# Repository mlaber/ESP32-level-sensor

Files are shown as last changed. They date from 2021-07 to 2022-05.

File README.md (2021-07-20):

# ESP32-level-sensor
ESP32 ultrasonic measurement for containers, reservoirs, silos ... with prometheus exporter
# ESP32 Ultraschall-Füllstandssensor 

*Messen von Füllständen und Pegel in Regenwasserzisternen, Pools, Fässern, Container, Silos ... mit Prometheus Exporter und einem Grafana Beispiel-Dashboard.*

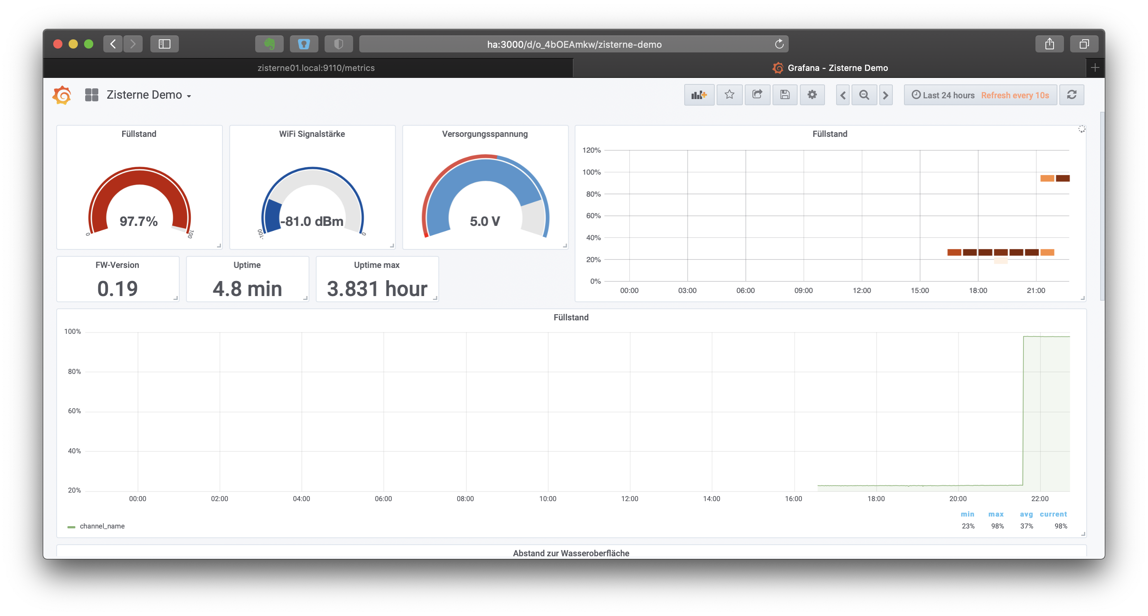
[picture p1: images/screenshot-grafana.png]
Grafana dashbaord
  
  
## Das Problem

 

Nachdem mein kapazitiver [Homematic Füllstandsmesser](https://de.elv.com/elv-homematic-komplettbausatz-kapazitiver-fuellstandsmesser-hm-sen-wa-od-fuer-smart-home-hausautomation-104945) bei einem starken Regen in unserer unterirdischen Zisterne geflutet wurde und ich dass ewige Wechseln der Batterien leid war, habe ich begonnen eine günstige Alternative auf Basis eines ESP32 zu entwickeln. Die Messwerte des Sensors werden via HTTP im [prometheus](https://prometheus.io) exporter-format bereitgestellt und können dann bequem archiviert und mit [Grafana](https://grafana.com) visualisiert werden. 

## Die Hardware

Neben einem ESP32 development board und einem Ulraschallsensor, hier ist der wasserdichte [JSN-SR0T4 Ultraschallsensor](https://www.amazon.de/DollaTek-Wasserdichter-Ultraschall-Abstandssensor-Messwandler-Modul-Arduino/dp/B07PMGJ231) dem günstigeren und nicht geschützen HC-SR04 deutlich überlegen, braucht man noch 2x10 kOhm Wiederstände für den Spannungsteiler um die Eingangsspannung zu überwachen. Wer den ESP mit einem 5V Netzteil betreibt kann auch auf die Wiederstände und die Messung der Versorgungsspannung verzichten.

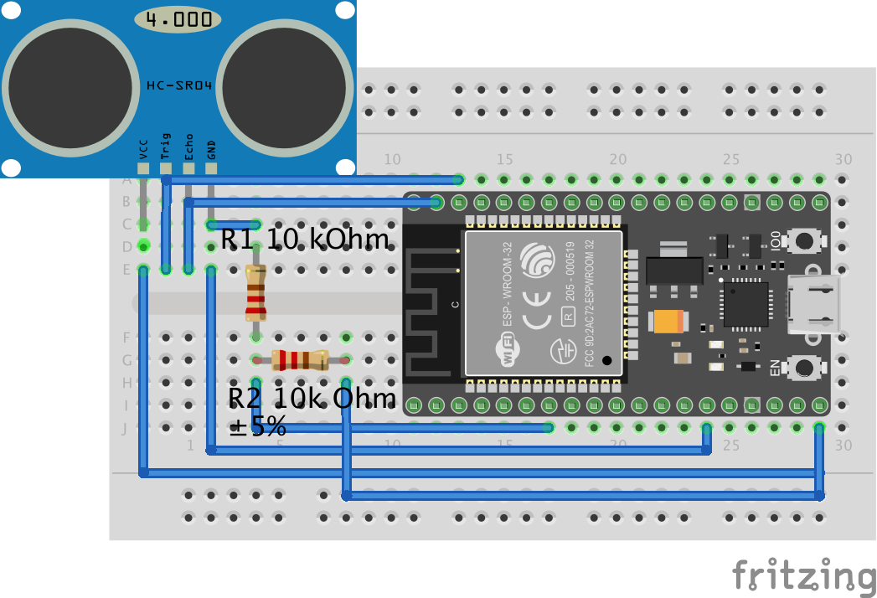
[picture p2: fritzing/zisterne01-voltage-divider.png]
Fritzing with voltage divider


## Aufbau und Installation

Der ESP samt Breakoutboad des Ultraschallsensor passt gut in eine etwas größere Aufputz-Abzweigdose. Die Gummimembranen von hochwertigen Abzweigdosen (3-5 € im Baumarkt) erlauben es den Stecker des Ultaschallsensor und ggf. die Zuleitung der Versorgungsspannung wasserdicht in das Gehäuse einzuführen.
Ich habe die Dose an einer zuvor installierten Holzstrebe geschraubt und einen kleine Ausleger für den Fühler des Sensors angebaut. **Wichtig: Stellt sicher dass der Sensor "freie Sicht" auf die Wasseroberfläche hat. Rohre, Kabel o.ä. im Streubereich des Sensors (ca. 20-30 cm um den Sensor) können die Messung verfälschen.**

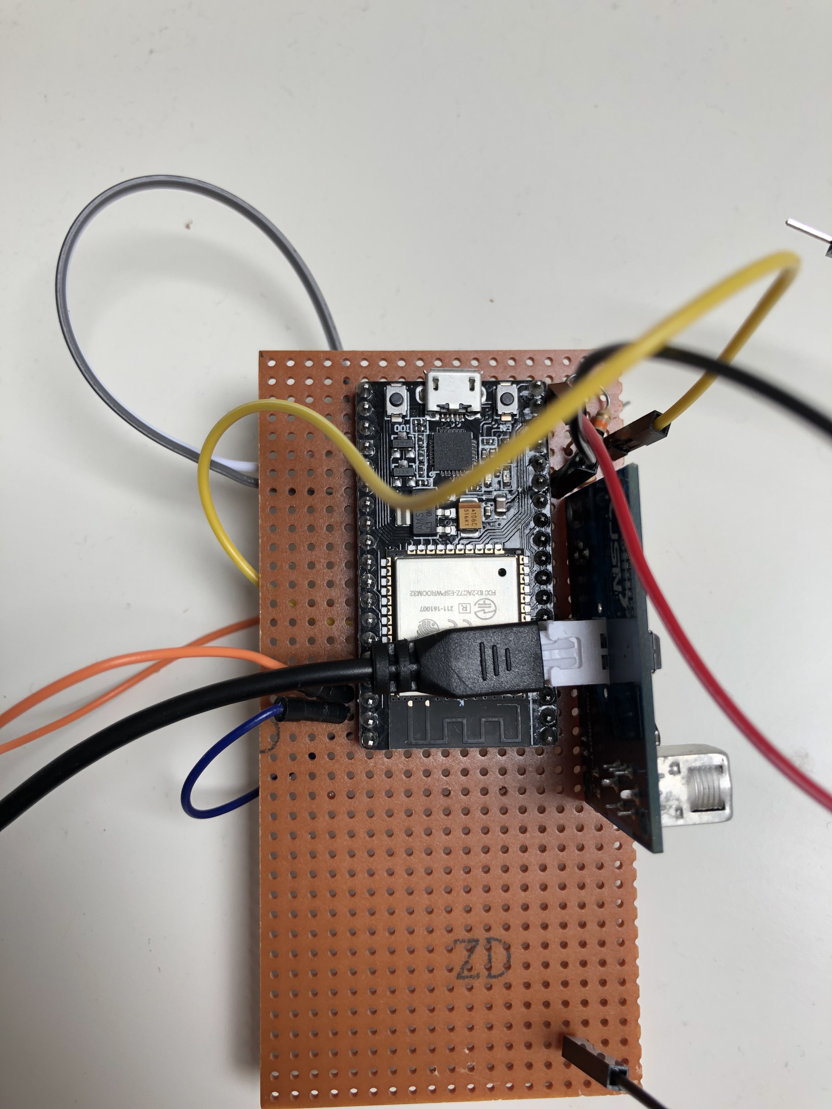
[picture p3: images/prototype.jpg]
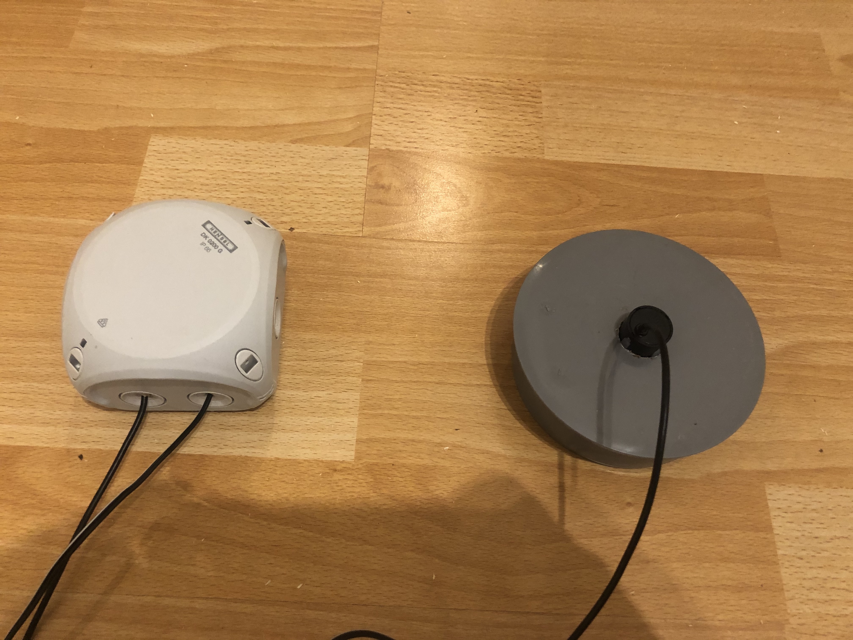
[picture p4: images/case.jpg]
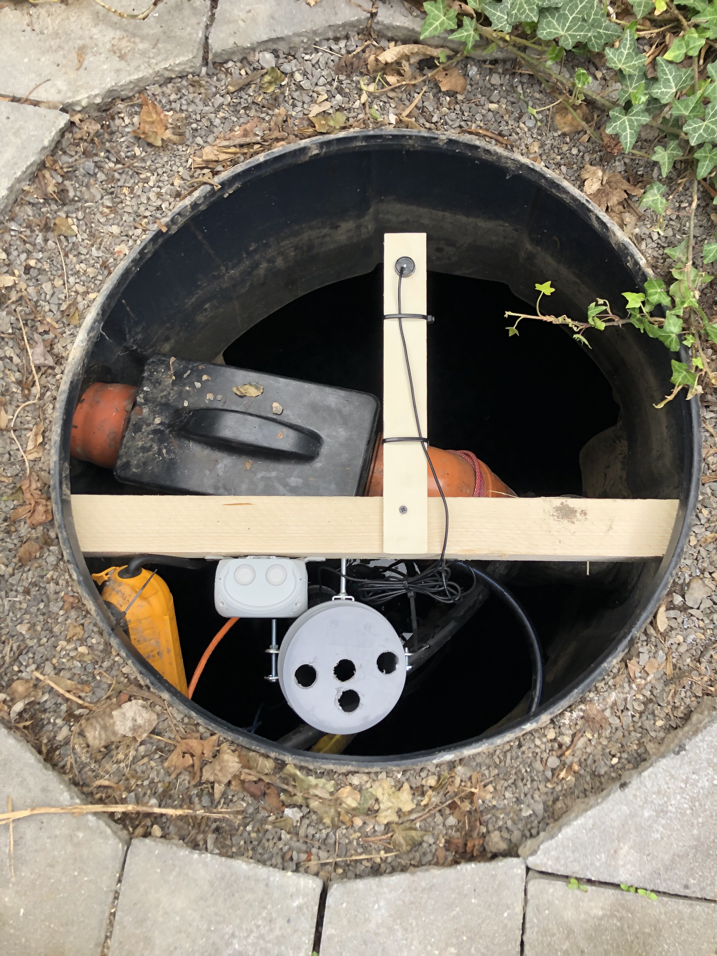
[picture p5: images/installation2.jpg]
   
 
## Konfigurieren und kompilieren

Passt die Einträge wie:

* WiFi Netzwerkname und Passwort
* Hostname - unter diesem Namen könnt ihr über mdns im format HOSTNAME.local auf den Webserver zugreifen. Möglicherweise erzeugt euer Router auf Basis der DHCP Adressvorgabe an den ESP automatisch einen internen DNS-Eintrag z.B. zisterne.fritz.box bei AVM Routern.
* min_level, max_level untere bzw. obere Füllstandgrenze der Zisterne in cm 

im header der der main.cpp an und kompiliert den sketch mit arduino oder platformio. Nachdem ersten kompilieren wird der enstandene Binärcode via USB auf den ESP Microcontroller übertragen. Der Code ist OTA fähig, so dass zukünftige Updates - ohne USB-Kabel over-the-air übertragen werden können.

## Datacollection

Auf Port 9110 (konfigurierbar) werden die Messwerte des Sensors und weitere nützliche Metriken, wie die WiFi-Signalstärke, Höhe der Versorgungsspannung, uptime, usw. exportiert.
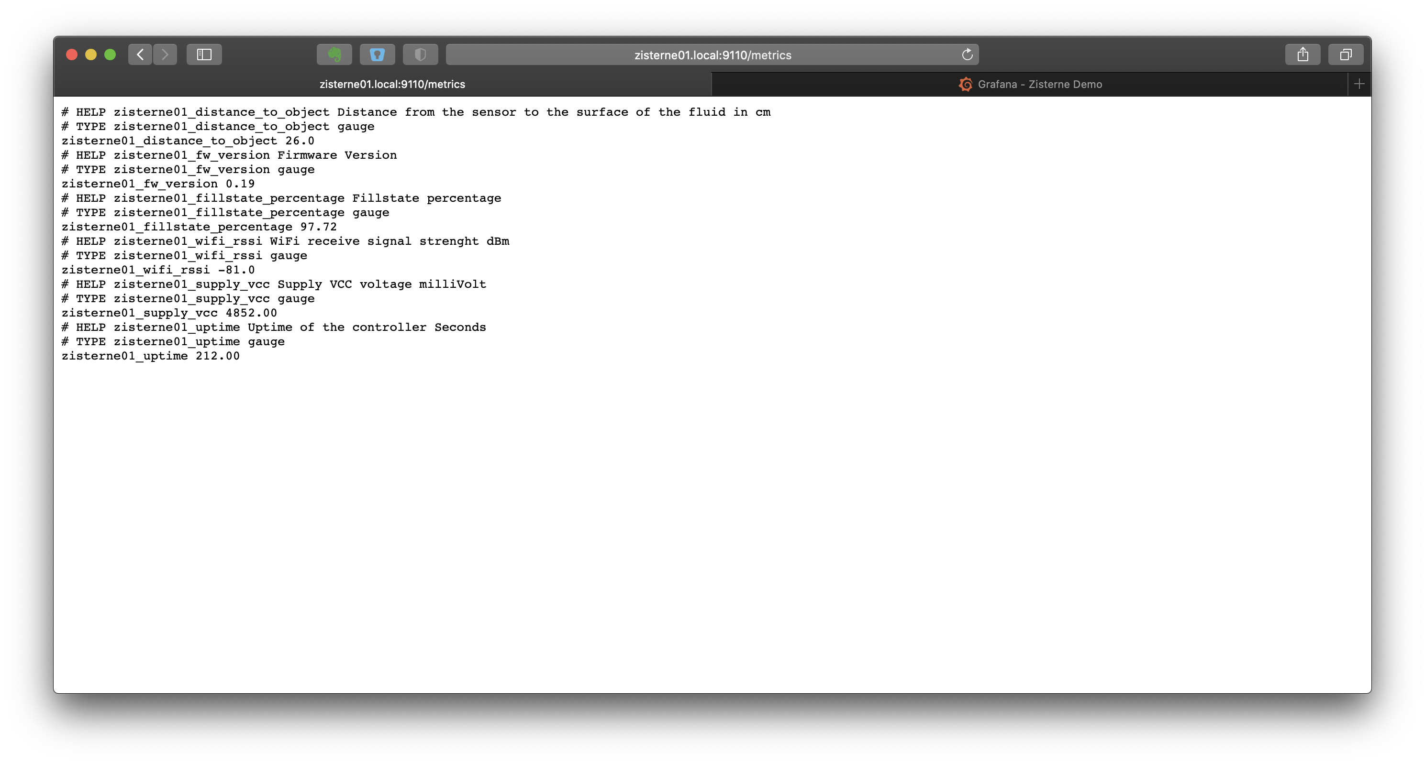
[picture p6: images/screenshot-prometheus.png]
prrometheus exporter format
Das verwendete  kann leicht aufgeparst werden und in beliebige andere Automatisierungslösungen eingebunden werden. 

Wenn ihr bereits einen prometheus server am laufen habt könnt ihr eure *prometheus.yml* wie folgt erweitern und die Metriken langfristig archivieren. Der Name des Targets muss dem von euch in der main.cpp konfigurierten hostname entsprechen.

 > - job_name: 'Zisterne'
 >   static_configs:
 >     - targets: ['zisterne01.fritz.box:9110']`

  ## Visualisierung
  
  Landen die Daten erstmal in prometheus können mit Grafana schnell ansprechende Dashboards erstellt werden.
  
  Grafana dashbaord

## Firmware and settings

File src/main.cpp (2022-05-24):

//Zisterne Fuellstand

//*********************************************************************************************************
//
// first release on 05/2021
// Version 0021 , May 19 2022
//


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
//

//**************************************************************************************************
//                                           LIBRARIES                                             *
//**************************************************************************************************


#include <Arduino.h>
#include <WiFi.h>
#include <ESPmDNS.h>
#include <WiFiUdp.h>
#include <ArduinoOTA.h>
#include <WebServer.h>
#include <prometheus_metric.h>
#include <esp_task_wdt.h>



//**************************************************************************************************
//                           PIN MAPPING                                                           *
//**************************************************************************************************
//GPIO22    Ultrasonoc Trigger pin
//GPIO23    Ultrasonic Echo pin
//GPIO32    Supply voltage / battey voltage sensor (optional)  ADC2_CH4  connect via 10k resistors in a voltage provider 5V VCC = 


int triggerPin = 22;
int echoPin = 23;
int VCCsensor = 32;

//**************************************************************************************************
//                                    VARIABLES AND CONSTANTS                                       *
//**************************************************************************************************



// Enter your parameters here: //
const char* ssid = "YOUR_SSID";                // WLAN SSID
const char* password = "YOUR_PASSWORD";                    // WLAN password
const char* hostname ="zisterne01";            // DNS hostname of the ESP also used as prefix for prometheus metric name
int port = 9110;                              // TCP port for prometheus exporter webserver see https://github.com/prometheus/prometheus/wiki/Default-port-allocations for default ports.
int ota_port = 3232;                          // TCP port for OTA Updates
int samplerate = 10;                          // 1..10 Samples that ave to been taken to calculate a average metric
int watchdog_timeout = 90;                    // Seconds before a blocking task leads to a watchdog reset
float min_level = 173.0;                       // distance to level of fluid in the reservoir in cm, the level where the pump dry-run protection shuts down the pump
float max_level = 28.0;                      // distance level of fluid in the reservoir in cm, the level where the fluid is drained by the overflow 
// End of parameters //

float version = 0.21;
float level_percentage = 0.0;
float cmDistance;     // Distance from the sensor to the surface of the fluid
float cmHeight;       // Height of the fluid in reservoir
float distance; 
float vcc = 0.0;            // calcutlated supply voltage from ESP ADC.
unsigned long duration;
unsigned long avg_duration;
unsigned long previous_time = 0;
unsigned long wifi_connection_delay = 20000;  // wait 20 seconds for wifi connection
long rssi;           // WiFi RSSI signal strength
float uptime;        // Controller Uptime



Metric distance2object(MetricType::gauge, "distance_to_object", "Distance from the sensor to the surface of the fluid in cm", 1, hostname); 
Metric fwversion(MetricType::gauge, "fw_version", "Firmware Version", 2, hostname); // 2 means to decimal places, hostname is the prefix for prometheus name
Metric fillstatepercentage(MetricType::gauge, "fillstate_percentage", "Fillstate percentage", 2, hostname); // 2 means to decimal places
Metric wifirssi(MetricType::gauge, "wifi_rssi", "WiFi receive signal strenght dBm", 1, hostname); 
Metric supplyvcc(MetricType::gauge, "supply_vcc", "Supply VCC voltage milliVolt", 2, hostname ); 
Metric controller_uptime(MetricType::gauge, "uptime", "Uptime of the controller Seconds", 2, hostname); 

WebServer server(port);


//**************************************************************************************************
//                                          FUNCTIONS                                              *
//**************************************************************************************************

long getUptime() {
  long uptime = esp_timer_get_time() / 1000000;   // https://docs.espressif.com/projects/esp-idf/en/latest/esp32/api-reference/system/esp_timer.html
    //Serial.println("------------------------------------");
    //Serial.print  ("Controller uptime       "); Serial.print(uptime); Serial.println(" seconds");
    //Serial.println("------------------------------------"); 
    return(uptime);
}


long getWiFiRSSI() {
  rssi = WiFi.RSSI();
  Serial.println("------------------------------------");
  Serial.print  ("WiFi Signal strength:       "); Serial.print(rssi); Serial.println(" dBm");
  Serial.println("------------------------------------"); 
  return(rssi);
}


int getVCCvoltage(){
  float vcc_raw = analogReadMilliVolts(VCCsensor);
  vcc = (vcc_raw * 2.0); // * 2.0  because the voltage divider, divides the currency on the GPIO pin by 2
  Serial.println("------------------------------------");
  Serial.println("Supply voltage:       "); Serial.print(vcc); Serial.println(" mV");
  Serial.println("------------------------------------"); 
  return(vcc);
}

int getUltrasonicDistance(){
  avg_duration = 0;
  int i = 0;
  int non_zero_value = 0;
  while(i < samplerate) {
    digitalWrite(triggerPin, HIGH);
    delayMicroseconds(10);
    digitalWrite(triggerPin, LOW);
    duration = pulseIn(echoPin, HIGH);

    if (duration > 0)   {     // 0 Values are physical very unlikely and should be ignored
      non_zero_value ++;
      avg_duration = avg_duration + duration;
    }  
    delay(30);              // 30 ms =  102 meters distance
    i++;
    }

  // Speed of sound in air: 343m/S (at 20°C)
  // 343,2 m/S --> 34,32cm / ms --> 0,03432cm / µs
  // divided by 2 because of the relection from the surface
  cmDistance = (avg_duration / non_zero_value) * 0.03432 / 2; 
  Serial.println("------------------------------------");
  Serial.print  ("Non Zero samples: "); Serial.print(non_zero_value); Serial.print  (" of total samples: "); Serial.println(samplerate);
  Serial.println("------------------------------------");

  Serial.println("------------------------------------");
  Serial.print  ("Distance:       "); Serial.println(cmDistance);
  Serial.println("------------------------------------");
  level_percentage = 100.0 / (min_level - max_level) * (min_level - cmDistance);
  Serial.println("------------------------------------");
  Serial.print  ("Fillstate:       "); Serial.print(level_percentage); Serial.println("%");
  Serial.println("------------------------------------"); 
  delay(200);
  return cmDistance;
  }

  

void handleRoot() {
  server.send(200, "text/html", "<a href=\"/metrics\">metrics</a>");
}

void handleMetrics() {                // Provide prometheus metrics under /metrics - the expected URI for the prometheus scraper
  String response = "";
  distance = getUltrasonicDistance();
  distance2object.setValue(distance);
  fwversion.setValue(version);
  fillstatepercentage.setValue(level_percentage);
  long rssi = getWiFiRSSI();
  wifirssi.setValue(rssi);
  vcc = getVCCvoltage();
  supplyvcc.setValue(vcc);
  uptime = getUptime();
  controller_uptime.setValue(uptime);

  response = distance2object.getString() + fwversion.getString() + fillstatepercentage.getString() + wifirssi.getString() + supplyvcc.getString() + controller_uptime.getString(); // Concat al the metrics
  server.send(200, "text/plain; version=0.0.4", response); 
}

//**************************************************************************************************
//                                           S E T U P                                             *
//**************************************************************************************************

void setup() {
  Serial.begin(115200);

  Serial.println("Configuring ESP32 task watchdog (WDT)...");     //https://docs.espressif.com/projects/esp-idf/en/latest/esp32/api-reference/system/wdts.html
  esp_task_wdt_init(watchdog_timeout, true); //enable panic so ESP32 restarts
  esp_task_wdt_add(NULL); //add current thread to WDT watch
  pinMode(triggerPin, OUTPUT);
  pinMode(echoPin, INPUT);


  Serial.print("Version: ");
  Serial.println(version);

  Serial.println("Initializing sensor");
  getUltrasonicDistance();
  getWiFiRSSI();
  getVCCvoltage();


  // Connect WiFi
  Serial.print("Connecting to ");
  Serial.println(ssid);
  
  WiFi.config(INADDR_NONE, INADDR_NONE, INADDR_NONE); // workarround to use hostname for dhcp client
  WiFi.mode(WIFI_STA);
  WiFi.hostname(hostname);
  WiFi.begin(ssid, password);

  while (WiFi.waitForConnectResult() != WL_CONNECTED) {
    Serial.println("Connection Failed! Rebooting...");
    delay(5000);
    ESP.restart();
  }

 
 ArduinoOTA
    .onStart([]() {
      String type;
      if (ArduinoOTA.getCommand() == U_FLASH)
        type = "sketch";
      else // U_SPIFFS
        type = "filesystem";

      // NOTE: if updating SPIFFS this would be the place to unmount SPIFFS using SPIFFS.end()
      Serial.println("Start updating " + type);
    })
    .onEnd([]() {
      Serial.println("\nEnd");
    })
    .onProgress([](unsigned int progress, unsigned int total) {
      Serial.printf("Progress: %u%%\r", (progress / (total / 100)));
    })
    .onError([](ota_error_t error) {
      Serial.printf("Error[%u]: ", error);
      if (error == OTA_AUTH_ERROR) Serial.println("Auth Failed");
      else if (error == OTA_BEGIN_ERROR) Serial.println("Begin Failed");
      else if (error == OTA_CONNECT_ERROR) Serial.println("Connect Failed");
      else if (error == OTA_RECEIVE_ERROR) Serial.println("Receive Failed");
      else if (error == OTA_END_ERROR) Serial.println("End Failed");
    });
  ArduinoOTA.setPort(ota_port);
  ArduinoOTA.setHostname(hostname);
  ArduinoOTA.begin();
  Serial.print("OTA Port: ");
  Serial.println(ota_port); 
  Serial.print("IP address: ");
  Serial.println(WiFi.localIP());
  Serial.print("Prometheus exporter URL: http://");
  Serial.print(hostname);
  Serial.print(".local:");
  Serial.println(port);
  Serial.println("Ready");


  server.on("/", handleRoot);
  server.on("/metrics", handleMetrics);
  server.begin();
  Serial.printf("HTTP server started on port %d\n",port);
}



//**************************************************************************************************
//                                          MAIN                                                   *
//**************************************************************************************************
  
void loop(){
  unsigned long current_time = millis(); // number of milliseconds since the upload
  ArduinoOTA.handle();     // Handler for Over The Air firmware updates
  esp_task_wdt_reset();     // Reset the task watchdog because we are still runnning ...
  server.handleClient();

   // checking for WIFI connection
  if ((WiFi.status() != WL_CONNECTED) && (current_time - previous_time >=wifi_connection_delay)) {
    Serial.print(millis());
    Serial.println("Reconnecting to WIFI network");
    WiFi.disconnect();
    WiFi.reconnect();
    previous_time = current_time;
  }

}

void handleRoot();

void handleMetrics();
